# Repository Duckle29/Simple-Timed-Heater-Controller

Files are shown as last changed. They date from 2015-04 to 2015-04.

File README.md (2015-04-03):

# Simple-Timed-Heater-Controller
A simple controller used to manage electrical heaters in for example a shed.
This code is compatible with any arduino board. It has however only been tested on my own hardware.

### Libraries used
In order to use the firmware, you will need to have the following libaries in your library folder:

* [LiquidTWI2](https://github.com/lincomatic/LiquidTWI2)
* [Encoder by PJRC](https://www.pjrc.com/teensy/td_libs_Encoder.html)

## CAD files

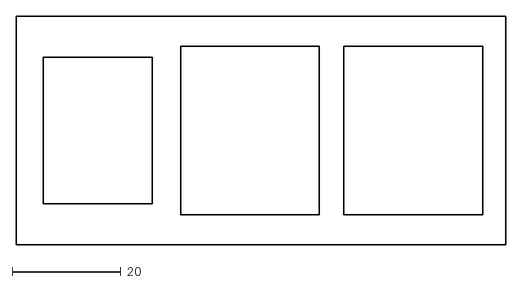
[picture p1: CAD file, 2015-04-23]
hardware/bottomplatecutouts.dxf
90.0 x 42.0

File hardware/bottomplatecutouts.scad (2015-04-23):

draw_switch_plates = false;
projection(cut=false)
{
difference()
{
  cube([90, 42, 1], center = true);
  translate([-2, 0,0]) cube([25.5, 31, 1], center = true);
  translate([-30, 0,0]) cube([20, 27,1], center = true);
  translate([28, 0,0]) cube([25.5, 31, 1], center = true);
}
}

if(draw_switch_plates)
{
  translate([-30, 0,2]) color("blue", 1.0) cube([24, 31.1,1], center = true);
  translate([-2, 0,2]) color("red", 1.0) cube([27.8, 35.2,1], center=true);
  translate([28, 0,2]) color("green", 1.0) cube([27.8, 35.2,1], center=true);
}

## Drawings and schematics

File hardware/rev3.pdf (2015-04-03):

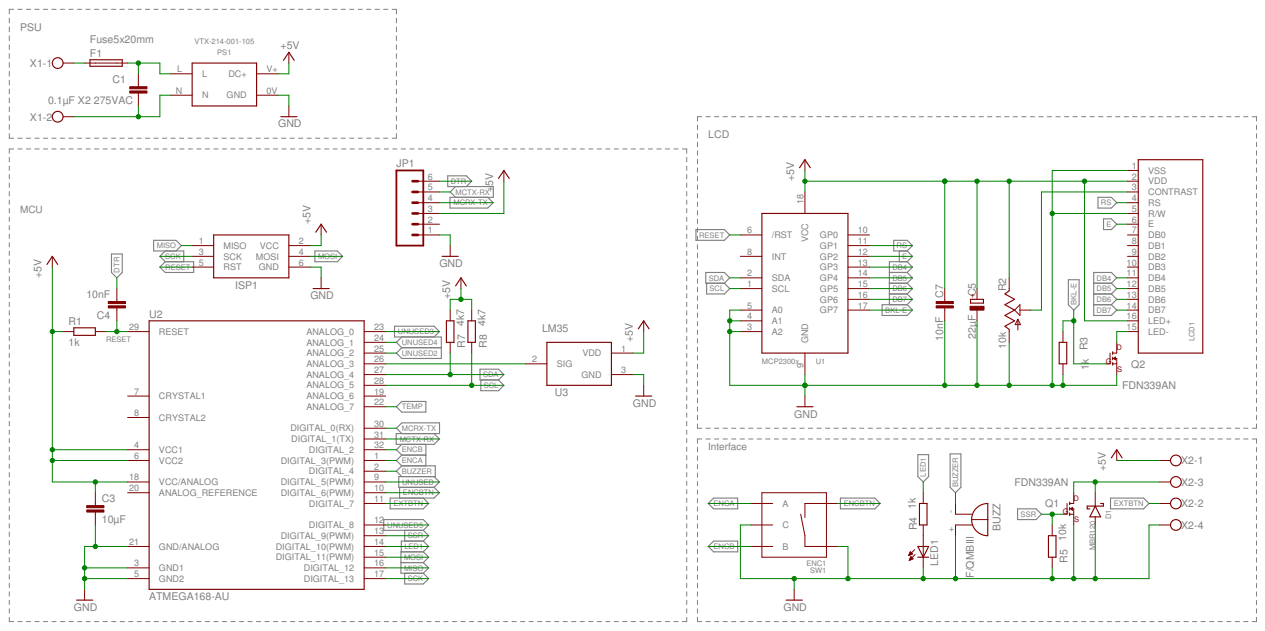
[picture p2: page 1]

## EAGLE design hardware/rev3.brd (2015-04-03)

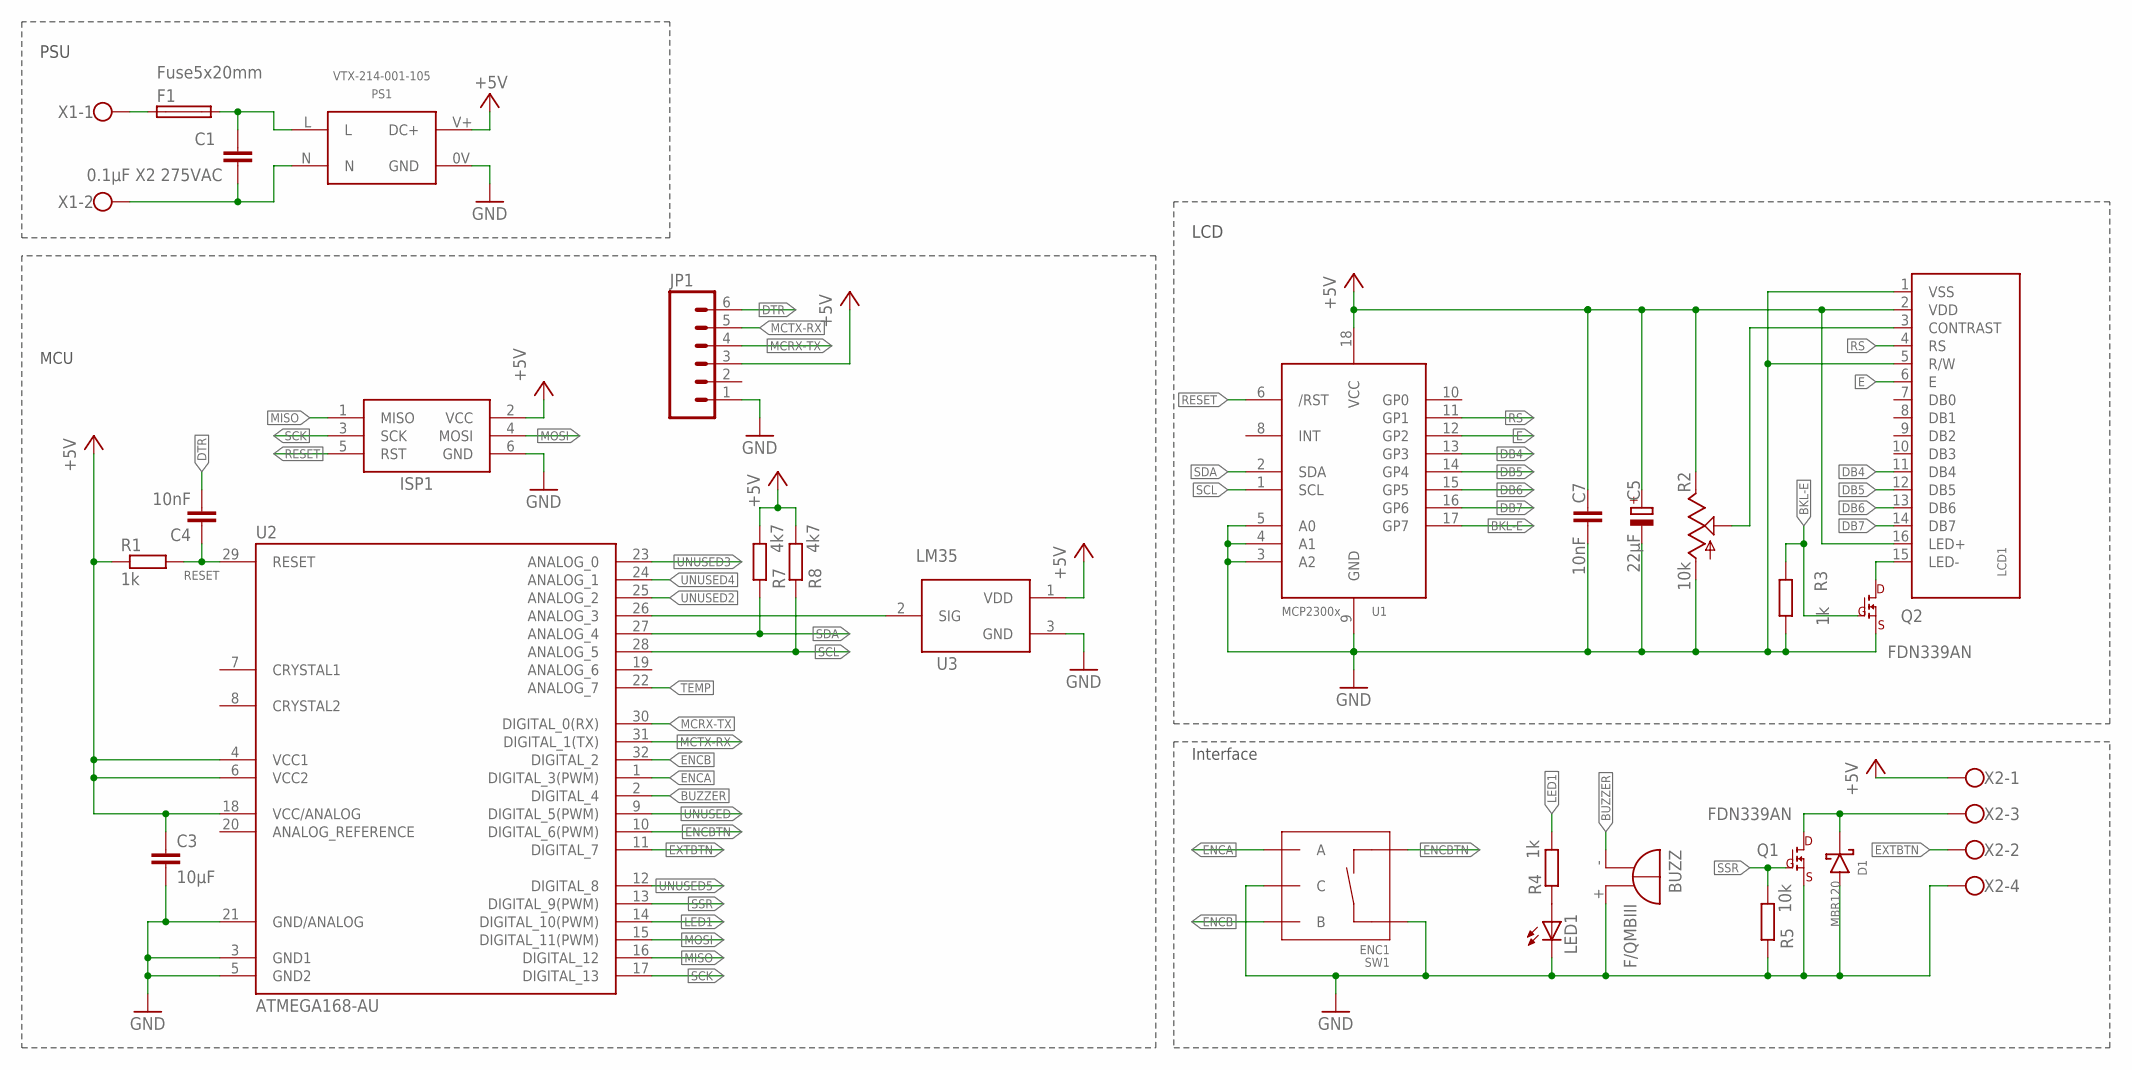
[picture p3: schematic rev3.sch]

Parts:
BUZZ: F/QMBIII
C1: 0.1µF X2 275VAC; C102-064X133
C3: 10µF; C3216
C4, C7: 10nF; C1206K
C5: 22µF; E2,5-6E
D1: MBR120; SOD-123FL
F1: Fuse5x20mm; FUSE_HOLDER_5X20MM
ISP1: AVRISP-6; AVRISP
JP1: M06LOCK; 1X06_LOCK
LCD1: HD44780-LCD; 8X2-CHARLCD
LED1: LED5MM
PS1: VTX-214-001-105; VTX-214-001-
Q1, Q2: FDN339AN; SOT23
R1, R3, R4: 1k; R0603
R2: 10k; B64Y
R5: 10k; R0603
R7, R8: 4k7; R0603
SW1: ENC1; ROTARY_ENC_PLAIN
U1: MCP2300X/SO; SO18W
U2: ATMEGA168-AU; TQFP32-08
U3: LM35; TO92-
X1: W237-113
X2: W237-4

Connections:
+5V: C3.1, C5.+, C7.1, ISP1.2 (VCC), JP1.3, LCD1.2 (VDD), LCD1.16 (LED+), PS1.V+ (DC+), R1.1, R2.E, R7.2, R8.2, U1.18 (VCC), U2.4 (VCC1), U2.6 (VCC2), U2.18 (VCC/ANALOG), U3.1 (VDD), X2.1
BKL-E: Q2.1 (GATE), R3.1, U1.17 (GP7)
BUZZER: BUZZ.- (+), U2.2 (DIGITAL_4)
DB4: LCD1.11 (DB4), U1.13 (GP3)
DB5: LCD1.12 (DB5), U1.14 (GP4)
DB6: LCD1.13 (DB6), U1.15 (GP5)
DB7: LCD1.14 (DB7), U1.16 (GP6)
DTR: C4.2, JP1.6
E: LCD1.6 (E), U1.12 (GP2)
ENCA: SW1.A, U2.1 (DIGITAL_3(PWM))
ENCB: SW1.B, U2.32 (DIGITAL_2)
ENCBTN: SW1.SW-, U2.10 (DIGITAL_6(PWM))
EXTBTN: U2.11 (DIGITAL_7), X2.2
GND: BUZZ.+ (-), C3.2, C5.-, C7.2, D1.A, ISP1.6 (GND), JP1.1, LCD1.1 (VSS), LCD1.5 (R/W), LED1.K (C), PS1.0V (GND), Q1.2 (SOURCE), Q2.2 (SOURCE), R2.A, R3.2, R5.1, SW1.C, SW1.SW+, U1.3 (A2), U1.4 (A1), U1.5 (A0), U1.9 (GND), U2.3 (GND1), U2.5 (GND2), U2.21 (GND/ANALOG), U3.3 (GND), X2.4
LED1: R4.2, U2.14 (DIGITAL_10(PWM))
MCRX-TX: JP1.4, U2.30 (DIGITAL_0(RX))
MCTX-RX: JP1.5, U2.31 (DIGITAL_1(TX))
MISO: ISP1.1 (MISO), U2.16 (DIGITAL_12)
MOSI: ISP1.4 (MOSI), U2.15 (DIGITAL_11(PWM))
unnamed: LCD1.3 (CONTRAST), R2.S
unnamed: F1.1, X1.1
unnamed: C1.1, F1.2, PS1.L
unnamed: LCD1.15 (LED-), Q2.3 (DRAIN)
unnamed: U2.26 (ANALOG_3), U3.2 (SIG)
unnamed: LED1.A, R4.1
unnamed: C1.2, PS1.N, X1.2
unnamed: D1.C, Q1.3 (DRAIN), X2.3
RESET: C4.1, ISP1.5 (RST), R1.2, U1.6 (/RST), U2.29 (RESET)
RS: LCD1.4 (RS), U1.11 (GP1)
SCK: ISP1.3 (SCK), U2.17 (DIGITAL_13)
SCL: R8.1, U1.1 (SCL), U2.28 (ANALOG_5)
SDA: R7.1, U1.2 (SDA), U2.27 (ANALOG_4)
SSR: Q1.1 (GATE), R5.2, U2.13 (DIGITAL_9(PWM))
TEMP: U2.22 (ANALOG_7)
UNUSED: U2.9 (DIGITAL_5(PWM))
UNUSED2: U2.25 (ANALOG_2)
UNUSED3: U2.23 (ANALOG_0)
UNUSED4: U2.24 (ANALOG_1)
UNUSED5: U2.12 (DIGITAL_8)

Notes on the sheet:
LCD
MCU
Interface
PSU

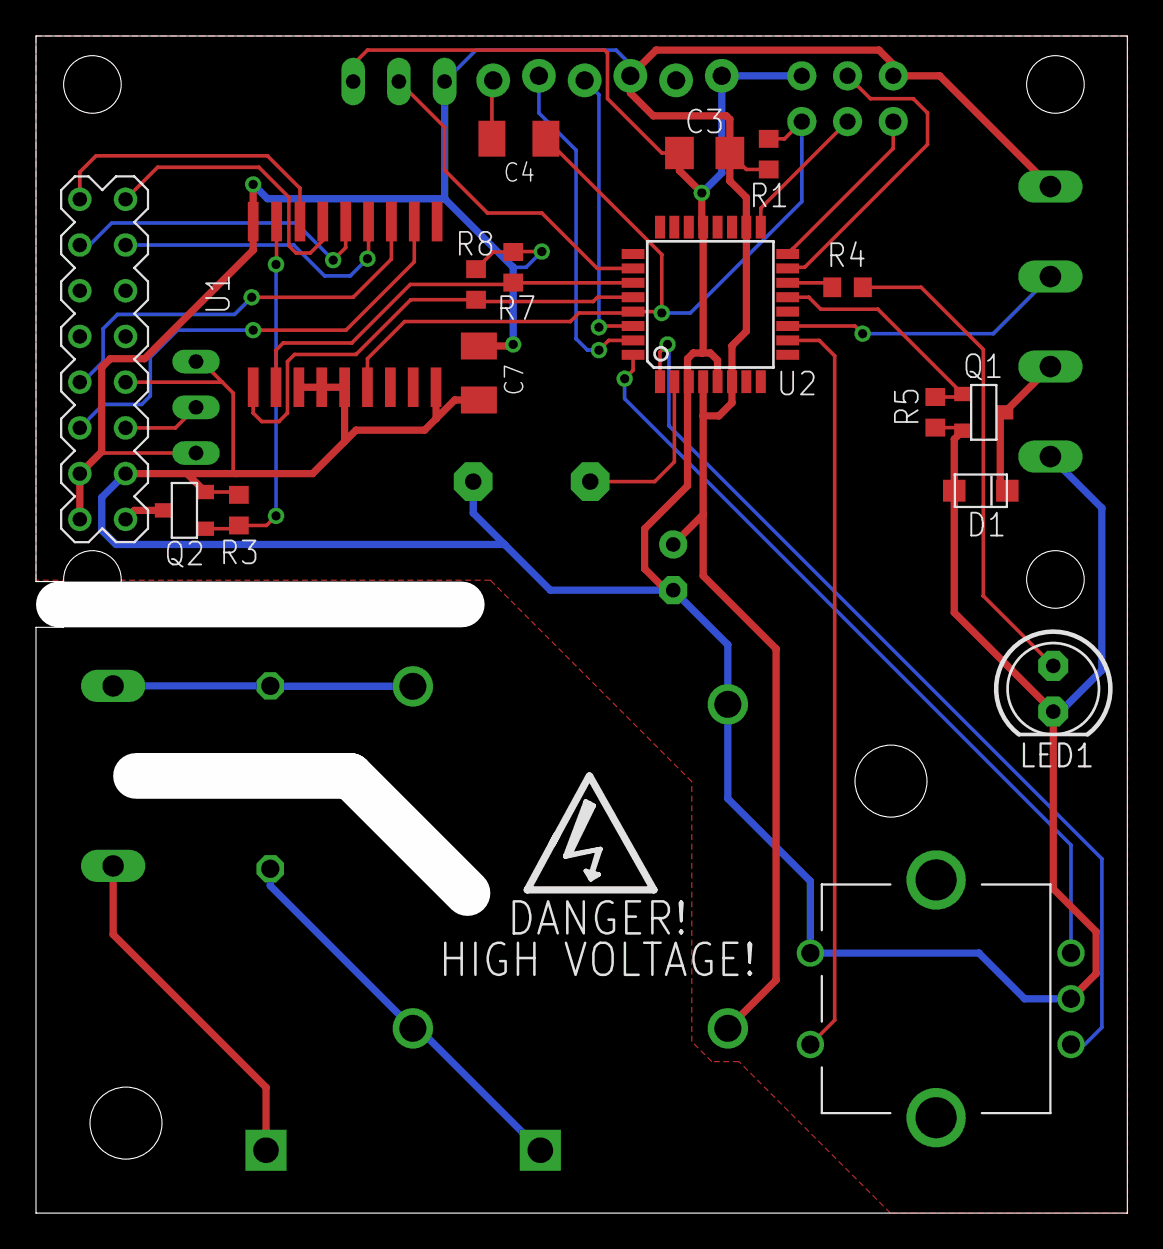
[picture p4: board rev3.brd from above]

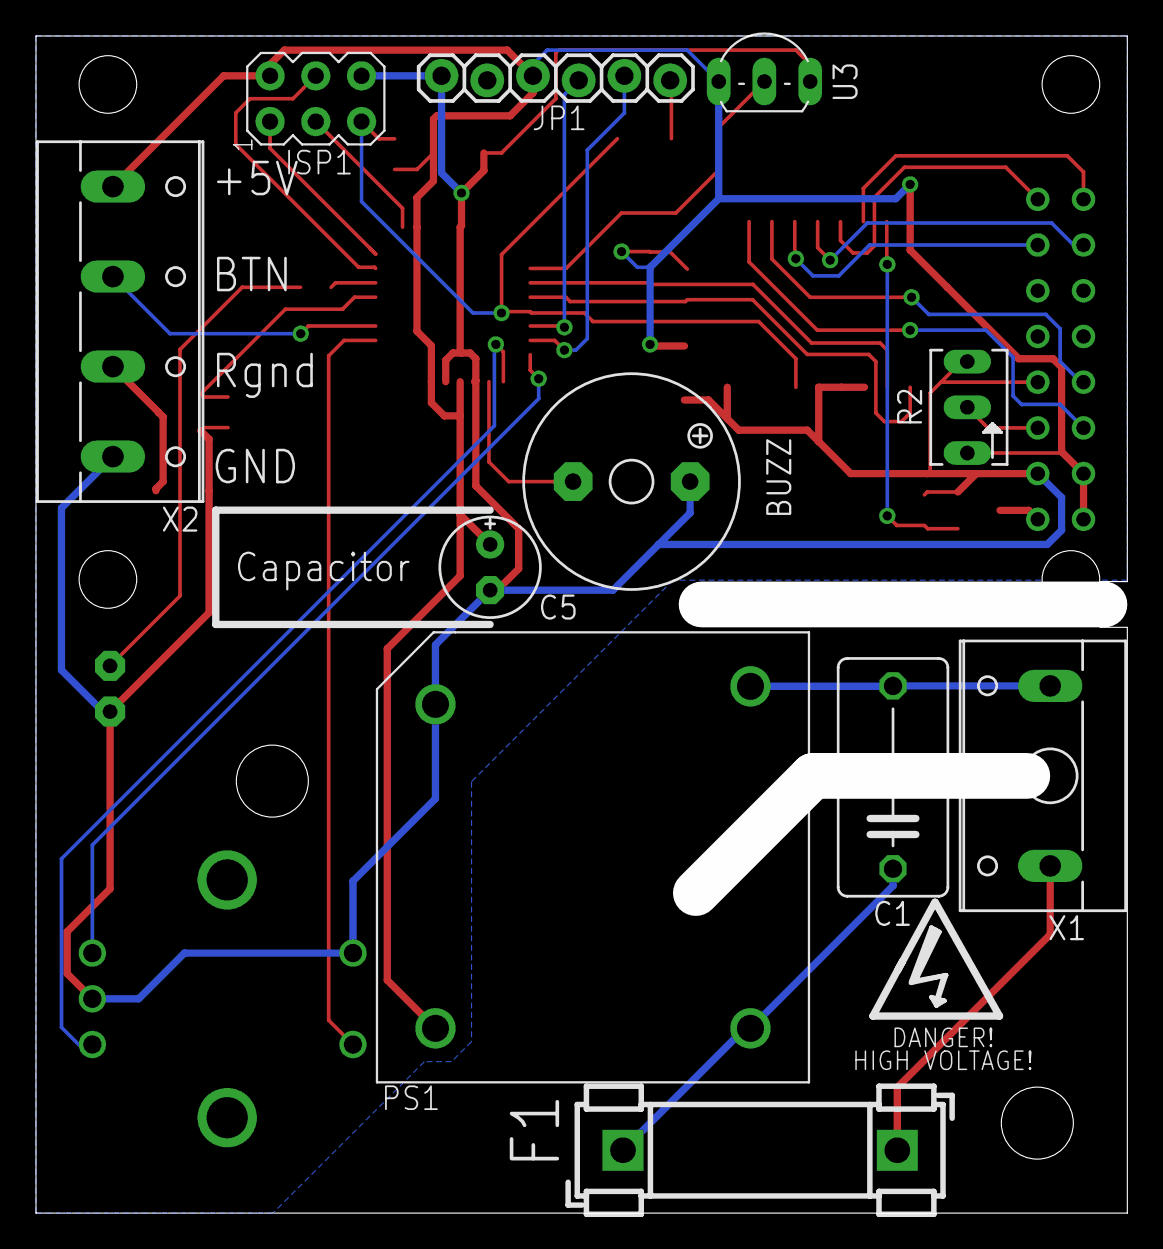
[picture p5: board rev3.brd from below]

Board: 2 copper layers, 60.6 x 65.4 mm, 28 parts (11 on the bottom side), 33 nets.

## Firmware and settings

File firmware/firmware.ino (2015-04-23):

/*
A radiator timer, for controlling radiators in a location that doesn't need them constantly on.

This was created for controlling the heating in our workshop.
It will try to keep the shop heated to a set value (8°C standard),
and if a button is pushed, will start heating up to a different set point (18°C standard)
for a set amount of time (2 hours standard)

Written by Mikkel DB Jeppesen 2014
TODO: License it under LGPL
*/

/*------------------------------
INCLUDED FILES UNDER HERE
------------------------------*/
#include <Wire.h>
#include <LiquidTWI2.h>
#include <Encoder.h>
#include <EEPROM.h>

/*------------------------------
PROTOTYPES HERE
------------------------------*/
int deBounce(int pin, int arrIndex, bool activeState = false);

/*------------------------------
VARIABLES UNDER HERE
------------------------------*/

// Store the different pins in variables
int tempSens = A3;
int extBtn = 7;
int encBtn = 6;
int SSR = 9;
int redLed = 10;
int buzzer = 4;

// Integers used in the program
int backLightDelay = 15*1000;
int buzzMs = 5;

int doubleclickInterval = 200; // Time in milliseconds you have to click again for it to be a double click
int pressDurationLong = 1000; // Time in milliseconds to press the button for it to be read as a long press
int bounceTime = 10; // Time to wait for a button to debounce in milliseconds

int standbyWarning = 5; // How many minutes before entering standby, should the buzzer start beeping? 0 = off.
int buzzInterval = 3000; // Time between buzzes in ms when the heater is about to enter standby mode

int encVal = 0;
int lastEncVal = 0;
int tempC;
int hysterisis = 2;
int btnStates[] = {0,0};
int buttons[] = {encBtn, extBtn};

// Temperature related control
float lastTempC = 0;
unsigned long tempChangedMs = 0;
unsigned long tempSettleTimeMs = 5*1000;
bool initialReadingDone = false;



// The set temperature (Using a byte, as I will only need two digit numbers, then it's easier to store in EEPROM)
byte setTemp = 8;

// Booleans
bool lastEncBtnState = false;
bool lastExtBtnState = false;
bool heaterState = false;
bool lastPinReading[] = {true, true};

// Different millis based delay effects
unsigned long heatTimeMinutes = 3;
unsigned long heatTimeMinutesLeft = 0;
unsigned long heatStartTime = 0;
unsigned long lastDebounceTime = 0;

unsigned long btnCountMsStart[] = {0,0};
unsigned long btnCountMs[] = {100,100};
unsigned long lastBtnClickMs[] = {0,0};

unsigned long lastMenuAction = 0;
unsigned long buzzStart = 0;
unsigned long lastBuzz = 0;

// Variables related to EEPROM
int offTempAdr = 0;
int onTempAdr = 2;
int timeAdrHighByte = 4;
int timeAdrLowByte = 5;

byte offTemp = 8;
byte onTemp = 18;
byte heatTimeHighByte = heatTimeMinutes / 256;
byte heatTimeLowByte = heatTimeMinutes % 256;


// Special variables under here
LiquidTWI2 lcd(0); // Connect via i2c, default address #0 (A0-A2 not jumpered)
Encoder ENC0(2, 3);
byte tempIcon[8] =
{
  0b00100,
  0b01010,
  0b01010,
  0b01110,
  0b01110,
  0b11111,
  0b11111,
  0b01110
};

/*------------------------------
SETUP FUNCTION UNDER HERE
------------------------------*/
void setup()
{
  Serial.begin(9600);

  lcd.setMCPType(LTI_TYPE_MCP23008);  // set the LCD type
  lcd.begin(8, 2);  // set up the LCD's number of rows and columns:
  lcd.createChar(0, tempIcon);

  // If custom values have been written to EEPROM, use those
  if(EEPROM.read(offTempAdr) != 255)
  {
    offTemp = EEPROM.read(offTempAdr);
  }
  if(EEPROM.read(onTempAdr) != 255)
  {
    onTemp = EEPROM.read(onTempAdr);
  }
  if(EEPROM.read(timeAdrLowByte) != 255)
  {
    heatTimeHighByte = EEPROM.read(timeAdrHighByte);
    heatTimeLowByte = EEPROM.read(timeAdrLowByte);

    heatTimeMinutes = heatTimeHighByte*256 + heatTimeLowByte;
  }

  setTemp = offTemp;

  // Set up the ATMega to use it's internal 1.1V referance, for greater accuracy on small ranges.
  analogReference(INTERNAL);

  // Set up the inputs and outputs
  pinMode(tempSens, INPUT);
  pinMode(encBtn, INPUT);
  pinMode(extBtn, INPUT);
  pinMode(buzzer, OUTPUT);
  pinMode(SSR, OUTPUT);
  pinMode(redLed, OUTPUT);

  digitalWrite(buzzer, LOW);

  // Turn on the internal pullups for the pins that need that
  digitalWrite(encBtn, HIGH);
  digitalWrite(extBtn, HIGH);

  lcd.setBacklight(LOW); // Turn off the backlight of the LCD (mainly for allowing low powered programmers to power the board)
}


/*------------------------------
MAIN CODE UNDER HERE
------------------------------*/
void loop()
{
  // Update the button state
  float tempTest = readTemp(tempSens);
  if(tempTest != -1.0)
  {
    tempC = (int)tempTest;
  }
  encVal = ENC0.read();
  displayControl();
  backlightManager();
  heaterControl();
  buzzControl();
  for(int i=0; i<2; i++)
  {
    btnStates[i] = deBounce(buttons[i], i);
  }
  /*
  if(btnStates[0] != 0 || btnStates[1] != 0)
  {
    Serial.print("enc: ");Serial.print(btnStates[0]);Serial.print(" ext\t");Serial.println(btnStates[1]);
  }
  */
}
/*------------------------------
FUNCTIONS UNDER HERE
------------------------------*/

float readTemp(int pin)
{
  int reading = analogRead(pin);
  float tempReadingC = (float)reading * 1100/1023 /10;

  if(tempC != lastTempC)
  {
    tempChangedMs = millis();
    lastTempC = tempC;
  }

  if(millis() - tempChangedMs > tempSettleTimeMs)
  {
    return tempReadingC;
  }
  else
  {
    if(!initialReadingDone)
    {
      initialReadingDone = true;
      return tempReadingC;
    }
    else
    {
      return -1.0;
    }
  }

}

// Function that controlls heater related functions, including the timing.
void heaterControl()
{
  // If the heater button is short-pressed. Reset the on time.
  if(btnStates[1] == -1)
  {
    heatStartTime = millis();
    heatTimeMinutesLeft = heatTimeMinutes;
    //buzzStart = millis();
  }

  // If the heater button is long-pressed. Set the time to 0.
  if(btnStates[1] == -2)
  {
    heatTimeMinutesLeft = 0;
    //buzzStart = millis();
  }

  // If it's currently in the heating mode, keep track of time, and set the target temperature
  // To the desired on temp, as chosen through the menu
  if(heatTimeMinutesLeft > 0)
  {
    int minutes = (millis()-heatStartTime)/60000;
    heatTimeMinutesLeft = heatTimeMinutes - minutes;
    setTemp = onTemp;

    // If in use. Buzz when a small amount of time is left, in case you wish to extend the timer.
    if(heatTimeMinutesLeft < standbyWarning)
    {
      if(millis() - lastBuzz > buzzInterval)
      {
        buzzStart = millis();
        lastBuzz = millis();
      }
    }

  }
  else // If the time has run out, set the temperature to the standby temp.
  {
    setTemp = offTemp;
  }

  if(tempC < setTemp-hysterisis)
  {
    heaterState = true;
  }
  if(tempC > setTemp+hysterisis)
  {
    heaterState = false;
  }

  digitalWrite(SSR, heaterState);
  digitalWrite(redLed, heaterState);
}

// Function that will return the number of digits in a passed number. For it's use in this program, it will add 1 to any negative numbers
int countDigits(long number)
{
  long result;
  int digits;

  // If the number is negative,
  if(number < 0)
  {
    result = -1 * number; // Multiply it by -1 (will flip it to positive)
    digits = 1; // And start out with digits as one (as there's a minus infront of the number)
  }
  else
  {
    result = number;
    digits = 0;
  }

  // While there's still digits left, devide by 10 and increment the digits variable
  while(result > 0)
  {
    result = result / 10;
    digits++;
  }
  return digits;
}

void buzzControl()
{
  if(millis() - buzzStart < buzzMs) // If the buzz is not yet over, write the buzzer pin high
  {
    digitalWrite(buzzer, HIGH);
  }
  else // Else write it low
  {
    digitalWrite(buzzer, LOW);
  }
}

// Debounce function used for debouncing buttons, and recognizing short, double, and long presses.
// It uses negative return values, for a future planned feature, where it will return how many fast clicks was done, instead of simply doubleclick.
int deBounce(int pin, int arrIndex, bool activeState)
{
  bool pinReading = digitalRead(pin); // Reading the current state of the pin
  unsigned long count = btnCountMs[arrIndex] - btnCountMsStart[arrIndex]; // Get the time the button was pressed

  if(pinReading != lastPinReading[arrIndex]) // If the pin state has changed
  {
    lastPinReading[arrIndex] = pinReading;
    if(pinReading != activeState && count > bounceTime) // If the button has been released after a debounce period.
    {
      if(count >= pressDurationLong) // If it was held for long enough to be considered a long press, return 2
      {
        return -2;
      }
      else // If it was less than that
      {
        if(millis() - lastBtnClickMs[arrIndex] < doubleclickInterval)
        {
          lastBtnClickMs[arrIndex] = millis();
          return 2; // If the button has been clicked fast twice, count it as a double click.
        }
        else
        {
          lastBtnClickMs[arrIndex] = millis();
          return -1; // If the button has only been pressed shortly, count it as a short-press.
        }
      }
    }
    btnCountMsStart[arrIndex] = millis(); // If the button has just been pressed, save the time it was pressed for later duration calculations
  }

  if(pinReading == activeState ) // As long as the button is pressed, keep track of what the millis is.
  {
    btnCountMs[arrIndex] = millis();
  }
  else
  if(count > bounceTime)
  {
    return 0;
  }
  return 0;
}

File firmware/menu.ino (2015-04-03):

/*
/	This file controls the menu system of the device, which allows the user to change settings such as
/	the different temperature setpoints, the timers duration and saving these to memory.
*/

// Array of strings (well pointers bleh) to use in the menu system.
char *settingsStrings[] = {"Back    ", "Off temp", "On  temp", "Time on ", "Save    "};

// Enum for what menu is configured
enum Menu
{
	none = 0,
	statusScreen,
	settings,
	lowTempEdit,
	highTempEdit,
	activeTimeEdit
};

Menu currentMenu = none;
Menu currentConfiguredMenu = none;

// Run the different menu functions depending on the current menu
void displayControl()
{
	switch (currentMenu)
	{
    case statusScreen:
      StatusScreen();
      break;

    case settings:
    	Settings();
    	break;

    case lowTempEdit:
    	LowTempEdit();
    	break;

    case highTempEdit:
    	HighTempEdit();
    	break;

    case activeTimeEdit:
    	ActiveTimeEdit();
    	break;

    default:
      currentMenu = statusScreen;
      StatusScreen();
      break;
	}
}

// Show the statusScreen
void StatusScreen()
{
		if(btnStates[0] == -1)
	{
		currentMenu = settings;
	}

	if(currentConfiguredMenu != statusScreen)
	{
		lcd.clear();
		lcd.setCursor(3,0);
        lcd.print("C");
        lcd.setCursor(7,0);
        lcd.print("C");
        lcd.setCursor(0,1);
		currentConfiguredMenu = statusScreen;
	}
	// Write the target temp (setTemp) (add a space if the number is less that 2 digits)
  lcd.setCursor(5,0);
  if(countDigits(setTemp) < 2)
  {
    lcd.print(" ");
  }
  lcd.print(setTemp);

	// Write the current temp (tempC) (add a space if the number is less that 2 digits)
  lcd.setCursor(0,0);
  lcd.write(byte(0));
  if(countDigits(tempC) < 2)
  {
    lcd.print(" ");
  }
  lcd.print(tempC);

  if(heatTimeMinutesLeft > 0)
  {
  	displayTime(heatTimeMinutesLeft, 1);
  }
  else
  {
  	lcd.setCursor(0,1);
  	lcd.print("Waiting ");
  }

}

// Show the different settings
void Settings()
{
	if(currentConfiguredMenu != settings) // If the user just entered this menu, display it.
	{
		lcd.clear(); // Clear the display
		lcd.setCursor(0, 0); // start from 0,0
		lcd.print("Setup"); // Print the current menu
		currentConfiguredMenu = settings; // The currently configured menu is now this menu
		ENC0.write(0);
	}
	encVal = ENC0.read() / 4; // Read the current position of the encoder
	lcd.setCursor(0,1);

	// Range limiting of the encoder value
	if(encVal > 4)
	{
		ENC0.write(0);
		encVal = 0;
	}
	if(encVal < 0)
	{
		ENC0.write(4*4);
		encVal = 4;
	}

	if(btnStates[0] == -1)
	{
		switch (encVal)
		{
		  case 0:
		  	currentMenu = statusScreen;
		    break;

		  case 1:
		  	currentMenu = lowTempEdit;
		  	break;

		  case 2:
		  	currentMenu = highTempEdit;
		  	break;

		  case 3:
		  	currentMenu = activeTimeEdit;
		  	break;

		  case 4:

  			if(EEPROM.read(offTempAdr) != offTemp)
  			{
     			EEPROM.write(offTempAdr, offTemp);
     			//Serial.print("LowTempSaved\n");
 			}

   			if(EEPROM.read(onTempAdr) != onTemp)
 			{
    			EEPROM.write(onTempAdr, onTemp);
    			//Serial.print("HighTempSaved\n");
 			}

 			heatTimeHighByte = heatTimeMinutes / 256;
			heatTimeLowByte = heatTimeMinutes % 256;

			if(EEPROM.read(timeAdrHighByte) != heatTimeHighByte)
			{
				EEPROM.write(timeAdrHighByte, heatTimeHighByte);
				//Serial.print("HighByteSaved\n");
			}
			if(EEPROM.read(timeAdrLowByte) != heatTimeLowByte)
			{
				//Serial.print("lowByteSaved\n");
				EEPROM.write(timeAdrLowByte, heatTimeLowByte);
			}


    		lcd.print("        ");
    		lcd.setCursor(0,1);
	    	lcd.print("Saved");
	    	delay(1500);
	    	//lcd.print(settingsStrings[encVal]);
	    	break;
		}
	}

	lcd.print(settingsStrings[encVal]);
}

// Allow the user to edit the low temperature setpoint
void LowTempEdit()
{
	if(currentConfiguredMenu != lowTempEdit) // If the user just entered this menu, display it.
	{
		lcd.clear(); // Clear the display
		lcd.setCursor(0, 0); // start from 0,0
		lcd.print(settingsStrings[1]); // Print the current menu
		lcd.setCursor(7,1);
		lcd.print("C");
		currentConfiguredMenu = lowTempEdit; // The currently configured menu is now this menu
		ENC0.write(offTemp*4);
	}
	encVal = ENC0.read() / 4;
	lcd.setCursor(5,1);

	if(encVal > 60)
	{
		encVal = 60;
		ENC0.write(60*4);
	}
	if(encVal < 0)
	{
		encVal = 0;
		ENC0.write(0);
	}

	if(countDigits(offTemp) < 2)
  {
    lcd.print(" ");
  }
  lcd.print(offTemp);
  offTemp = encVal;

  if(btnStates[0] == -1)
  {
  	currentMenu = settings;
  }
}

// Allow the user to edit the high teperature setpoint
void HighTempEdit()
{
	if(currentConfiguredMenu != highTempEdit) // If the user just entered this menu, display it.
	{
		lcd.clear(); // Clear the display
		lcd.setCursor(0, 0); // start from 0,0
		lcd.print(settingsStrings[2]); // Print the current menu
		lcd.setCursor(7,1);
		lcd.print("C");
		currentConfiguredMenu = highTempEdit; // The currently configured menu is now mainMenu
		ENC0.write(onTemp*4);
	}
	encVal = ENC0.read() / 4;
	lcd.setCursor(5,1);

	if(encVal > 60)
	{
		encVal = 60;
		ENC0.write(60*4);
	}
	if(encVal < 0)
	{
		encVal = 0;
		ENC0.write(0);
	}

	if(countDigits(onTemp) < 2)
  {
    lcd.print(" ");
  }
  lcd.print(onTemp);
  onTemp = encVal;

  if(btnStates[0] == -1)
  {
  	currentMenu = settings;
  }
}

// Allow the user to edit the time that it will stay on the high temperature setpoint, before resetting.
void ActiveTimeEdit()
{
	if(currentConfiguredMenu != highTempEdit) // If the user just entered this menu, display it.
	{
		lcd.clear(); // Clear the display
		lcd.setCursor(0, 0); // start from 0,0
		lcd.print(settingsStrings[3]); // Print the current menu
		currentConfiguredMenu = highTempEdit; // The currently configured menu is now mainMenu
		ENC0.write(heatTimeMinutes/5*4);
	}
	encVal = ENC0.read() / 4;

	if(encVal > 6000)
	{
		encVal = 6000;
		ENC0.write(6000*4);
	}
	if(encVal < 0)
	{
		encVal = 0;
		ENC0.write(0);
	}

	displayTime(heatTimeMinutes, 1);

	heatTimeMinutes = encVal*5;

	// If the encoder has been pushed, leave the submenu.
	if(btnStates[0] == -1)
  {
  	currentMenu = settings;
  }
}

// Control the backlight, and beep the buzzer with any action the user dows.
void backlightManager()
{
	if(ENC0.read()/4 != lastEncVal/4 || btnStates[1] != 0 || btnStates[0] != 0)
	{
		lastMenuAction = millis();
		lastEncVal = ENC0.read();
		buzzStart = millis();
	}

	if(millis()-lastMenuAction > backLightDelay)
	{
		lcd.setBacklight(false);
		currentMenu = statusScreen;
	}
	else
	{
		lcd.setBacklight(true);
	}
}
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

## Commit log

2015-04-03 Added hardware files
    [rev3.brd, rev3.sch]
2015-04-23 Added a temperature stabilisation test
    [bottomplatecutouts.dxf, bottomplatecutouts.scad]

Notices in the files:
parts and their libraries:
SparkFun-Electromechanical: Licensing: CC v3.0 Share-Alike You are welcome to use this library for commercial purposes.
